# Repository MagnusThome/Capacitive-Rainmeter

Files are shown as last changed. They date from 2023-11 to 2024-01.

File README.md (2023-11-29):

# Capacitive-Rainmeter
Measure rain intensity in Homeassistant with a capacitive sensor 

The code uses mqtt to send data and also for self-registering the sensor in Homeassistant. 

## Sensor:

__Capacitive Rain Sensor RC-SPC1K__  
https://radiocontrolli.eu/Capacitive-Rain-Sensor-RC-SPC1K-p242943346


Why a capacitive sensor? I've previously used those common resistive sensors that have copper traces that the rain falls on. The problem is that these boards tend to deteriorate after a while due to oxidization. There are tricks to minimize the problem, reducing the current and the duration the current is flowing, but in the end you still have metal and electrical current in a harsh environment. A capacitive sensor is totally electrically isolated from the rain and damp. By having no external electrically connected sensor parts the main problems with wear in an outdoor environment are removed. A bonus I found with the capacitive sensor I use is that it reacts much faster to changes in rain intensity compared to the resistive one I had previously. The new sensor also has a built in heater and an NTC resistor which means I can heat it up and control the temperature precisely during the winter. This is a clear plus in snowy Sweden.  
<br><br>   
The sensor's heater runs on 12V so that is the voltage you need to supply to your build. Any ESP32 board will do but since you need to run this on 12V you normally need a DC-DC buck converter to power the ESP32 at 5V. But these converters are cheap and easy to find. I happened to have an ESP32 board that can run on 12V natively so I just had to add a few components to interface it with the rain sensor. A basic schematic is included below on how to connect the different GPIOs. Also see the config.h file where you can specify what goes to what pin on your board.   
<br><br>   

When the sensor detects rain or snow the code keeps the sensor at around 45 degrees Celsius by sensing the NTC resistor value and turning the heater on and off (with a transistor) quite quickly around a small temperature hysteresis. Yeah, just how temperature control has been done since the stone age. I don't know if I've set it to its optimal temperature, to for example keep snow melting and also drying off rain not too fast and not too slow. I have a sensor installed and I log it in Homeassistant and I might tweak the code during the winter.
<br><br>  
The measurement of the capacitance is done by first making sure the capacitor/sensor is fully discharged by pulling the GPIO pin connected to it to ground. Then that pin is turned to a high impedance input and another pin goes high and starts charging the capacitor slowly through a 1Mohm resistor while the first pin is measuring the rising voltage directly on the capacitor. When the voltage reaches 63% of the full voltage the time between the start and stop of this charging sequence is saved. The larger the capacitance, when raining, the longer the charging time. 
<br><br>  
Parts used:  
  
- NPN transistor (I used a 2N2222A because I had one and it can handle the current of a bit under one ampere)  
- Two 1Kohm resistors  
- One 1Mohm resistor  
<br clear=all><br>

build


  
diagram

## Things to find out

- Should the sensor be mounted 100% horizontal or should it be tilted slightly? Will how it is mounted change if rain accumulates and stays long after it has stopped raining? Or does the heater handle that with my currently set temperature? Currently it is mounted a bit slanted and it seems to work very well..

- What temperature is best for the sensor's built in heater to run at? I guess the optimal is when it is warm enough to help dry off rain so when the rain stops the sensor will report "no rain" in a decent amount of time?

- The reported value seems a bit unlinear to what I see as heavy rain and drizzle and everything in between. But I have added some code for this, it "feels" quite reasonable so far but it might need some tweaking down the line?
   
## Schematic
  
  

<hr>

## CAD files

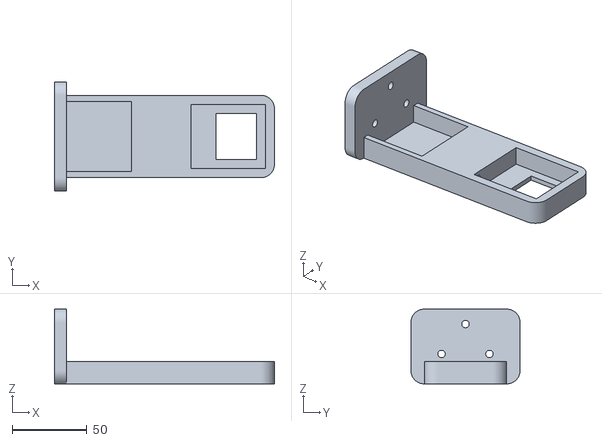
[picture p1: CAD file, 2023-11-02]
3dprint/Body.stl
147.0 x 73.0 x 50.0

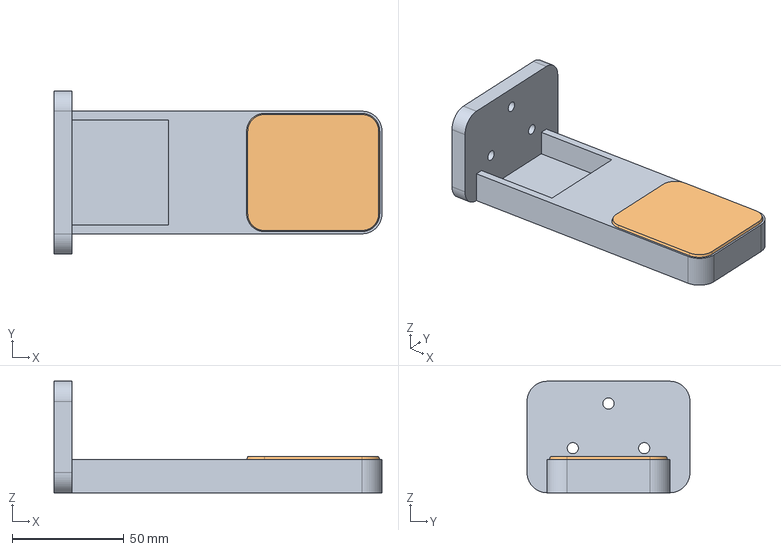
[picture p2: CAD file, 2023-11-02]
3dprint/Mount.step
147.0 x 73.0 x 50.0 mm

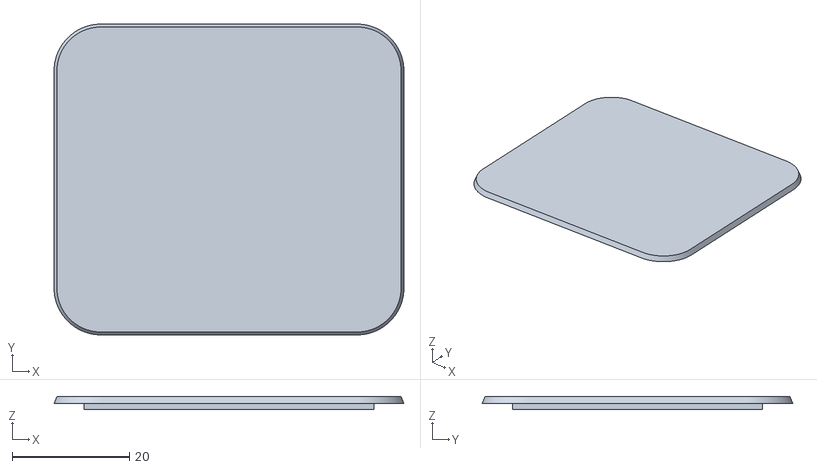
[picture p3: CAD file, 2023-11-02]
3dprint/Lid.stl
59.7 x 53.0 x 2.20

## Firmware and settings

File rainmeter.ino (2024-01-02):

#include <Arduino.h>
#include <WiFi.h>
#include <WiFiClient.h>
#include <WebServer.h>
#include <HTTPUpdateServer.h>
#include <PubSubClient.h>
#include <RunningMedian.h>
#include "config.h"


#define ANALOG_FULL_RANGE   4096
#define HEAT_HYSTERESIS     25


#define WEBPAGESIZE         1024
char webpage[WEBPAGESIZE];
#define MQTTBUFFSIZE        256
char mqttbuff[MQTTBUFFSIZE];

int rawresult;
int rainintensity;


WiFiClient client;
WebServer server(80);
HTTPUpdateServer httpUpdater;
PubSubClient mqttclient(client);

#define RUNNING_MEDIANS     60
RunningMedian measurements = RunningMedian(RUNNING_MEDIANS);   


// -------------------------------------------------------------------
void setup() {
  Serial.begin(115200);
                                
  Serial.setTxTimeoutMs(0);   // comment out for basic ESP32 variants with no on chip USB
                              // prevents slow serial prints on some ESP32 variants if CDC on boot is enabled, usb is connected but no terminal running
  
  pinMode(GPIO_HEATER, OUTPUT);
  pinMode(BLUE_LED, OUTPUT);
  pinMode(YELLOW_LED, OUTPUT);

  pinMode(GPIO_1MOHM, INPUT);
  pinMode(GPIO_CAPACITOR, OUTPUT);
  digitalWrite(GPIO_CAPACITOR, LOW);    // discharge the capacitor preparing it for the first measurement

  Serial.print("Connecting to wifi ");
  Serial.print(String(ssid));
  WiFi.setHostname(hostname);
  WiFi.begin(ssid, wifipassword);
  while (WiFi.status() != WL_CONNECTED) {
    delay(500);
    Serial.print(".");
    if (millis()>60000) {              // still no connection after one minute, reboot and retry
      ESP.restart();
    }
  }
  Serial.print(" done!\nSignal strength: ");
  Serial.println(String(WiFi.RSSI()));
  Serial.print("Webserver started at http://");
  Serial.println(WiFi.localIP());

  server.on("/", handlewebpage);
  server.begin();
  httpUpdater.setup(&server, ota_path, ota_username, ota_password);
  mqttclient.setServer(mqttserver, 1883);
  mqttConnect(); 
}



// -------------------------------------------------------------------
void loop() {

  unsigned long now = millis();

  server.handleClient();
  mqttclient.loop();
  
  static unsigned long timerone;
  if (now - timerone >= 50) {       // every 50ms
    timerone = now;
    heatercontrol();
  }

  static unsigned long timertwo;
  if (now - timertwo >= 1000) {     // every 1s
    timertwo = now;
    measurerain();
  }
  
  static unsigned long timerthree;
  if (now - timerthree >= 60000) {  // every 60s
    timerthree = now;
    mqttsend(rainintensity); 
  }
}



// -------------------------------------------------------------------
void measurerain (void) {

  unsigned long timerstart;
  
  heater_off();  // prevent overheating if stuck in the while loop below

  // -- stop discharging the now fully discharged capacitor by making gpio high impedance --
  pinMode(GPIO_CAPACITOR, INPUT); 

  // -- start charging the capacitor and measure the time to charge it to 63% --  
  pinMode(GPIO_1MOHM, OUTPUT);
  digitalWrite(GPIO_1MOHM, HIGH);
  timerstart = micros();
  while (analogRead(GPIO_CAPACITOR) < 0.63*ANALOG_FULL_RANGE);
  rawresult = (int)(micros()-timerstart);

  // Repackage result
  measurements.add(constrain(rawresult-CAPACITANCE_OFFSET, -500, 30000));     // remove offset and sanitize and then smooth and remove further outliers with the median array
  rainintensity = (int)(10*cbrt(max(measurements.getMedian(),(float)0.0)));   // make range feel more linear      
//  rainintensity = (int)(3*sqrt(max(measurements.getMedian(),(float)0.0)));  // make range feel more linear      

  // -- start discharging capacitor preparing it for the next measurement --  
  pinMode(GPIO_CAPACITOR, OUTPUT);
  digitalWrite(GPIO_CAPACITOR, LOW);
}



// -------------------------------------------------------------------
bool mqttConnect(void) {
  
  if (mqttclient.connected()) {
    return true;
  }
  Serial.print("Connecting to mqtt server ");
  Serial.print(String(mqttserver));
  if (mqttclient.connect(hostname, mqtt_username, mqtt_password)) {
    digitalWrite(BLUE_LED, HIGH);
    Serial.println(" done!");
    return true;
  } 
  digitalWrite(BLUE_LED, LOW);
  Serial.print(" failed, rc=");
  Serial.println(mqttclient.state());
  return false;
}



// -------------------------------------------------------------------
void mqttsend (int rain) {

  if (!mqttclient.connected()) {
    mqttConnect();
  }
  snprintf( mqttbuff, MQTTBUFFSIZE, "{\"~\":\"homeassistant/sensor/rainmeter\",\"name\":\"%s\",\"unique_id\":\"%s\",\"device_class\":\"precipitation_intensity\",\"stat_t\":\"~/state\"}", haName, haUniqid); 
  mqttclient.publish("homeassistant/sensor/rainmeter/config", mqttbuff);
  Serial.println(mqttbuff);
  snprintf( mqttbuff, MQTTBUFFSIZE, "%d", rain );
  mqttclient.publish("homeassistant/sensor/rainmeter/state", mqttbuff);
  Serial.println(mqttbuff);
}



// -------------------------------------------------------------------
void heatercontrol(void) {    
  int temperature = ANALOG_FULL_RANGE-analogRead(GPIO_NTC);
  if (temperature < HEAT_LEVEL && rainintensity>0) {    // only heat up the sensor if it detects rain or snow
      heater_on();
  }
  if (temperature > HEAT_LEVEL+HEAT_HYSTERESIS) {
      heater_off();
  }
}

void heater_on(void) {    
  digitalWrite(GPIO_HEATER, HIGH);
  digitalWrite(YELLOW_LED, HIGH);
}

void heater_off(void) {    
  digitalWrite(GPIO_HEATER, LOW);
  digitalWrite(YELLOW_LED, LOW);
}




// -------------------------------------------------------------------
void handlewebpage(void){

  static int max_offset = 0;
  static int max_rain = 0;

  max_offset = max((int)measurements.getMedian()+CAPACITANCE_OFFSET, max_offset);

  snprintf( webpage, WEBPAGESIZE, " \
  <html><head><meta http-equiv=refresh content=3></head><body><pre>\n \
  Hostname:     %s \n \
  Wifi signal:  %d dB \n \
  \n \
  Mqtt server:  %s \n \
  Connected:    %d \n \
  HA name:      %s \n \
  HA uniq_id:   %s \n \
  \n \
  \n \
  When the board is freshly rebooted and the sensor is \n \
  dry take the value from below and add to config.h \n \
  \n \
  <span style=\"color:#0c0;font-weight:bold;\">&#35;define CAPACITANCE_OFFSET %d </span>\n \
  \n \
  \n \
  Currently entered in config.h: \n \
  \n \
  <span style=\"color:#00e;font-weight:bold;\">&#35;define CAPACITANCE_OFFSET %d </span>\n \
  \n \
  \n \
  If the value of CAPACITANCE_OFFSET in config.h is set \n \
  slightly too low the reported rainintensity value will \n \
  occasionally rise above zero even whith no rain \n \
  \n \
  Current rainintensity: %d \n \
  </pre></body></html> \
  ", hostname, WiFi.RSSI(), mqttserver, mqttclient.connected(), haName, haUniqid, max_offset, CAPACITANCE_OFFSET, rainintensity ); 
  server.send(200, "text/html", webpage );
}




// --------------------------

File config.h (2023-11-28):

const char* ssid = "xxxxxxxx";
const char* wifipassword = "xxxxxxxx";
const char* hostname = "rainmeter";

const char* mqttserver = "xxxxxxxx";
const char* mqtt_username = "xxxxxxx";
const char* mqtt_password = "xxxxxxxx";

const char* ota_path = "/firmware";
const char* ota_username = "xxxxxxx";
const char* ota_password = "xxxxxx";

const char* haName   = "Rainmeter";
const char* haUniqid = "rainmeter01";

#define HEAT_LEVEL          2800    // 2500 ca 35 degrees celsius  //  2800 ca 45 degrees celsius

#define CAPACITANCE_OFFSET  200     // This is to zero out the summed capacitance of the cable and sensor when fully dry
                                    // Set this so the reported rainintensity stays at zero when the sensor is dry
                                    // Go to the device's local web page to get help finding the correct value
#define BLUE_LED        10
#define YELLOW_LED      11

#define GPIO_NTC        1           // Needs to be a GPIO pin that has ADC capabilites
#define GPIO_HEATER     48
#define GPIO_CAPACITOR  2           // Needs to be a GPIO pin that has ADC capabilites
#define GPIO_1MOHM      41

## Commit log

2023-11-10 fiddling with filter
2023-11-29 heater on only when damp
